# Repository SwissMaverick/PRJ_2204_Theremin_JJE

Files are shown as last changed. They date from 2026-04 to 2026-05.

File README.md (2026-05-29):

# README du projet 2204 Thérémine version 3
## Objectif du projet
Le Théremin est un appareil permettant de générer un signal audible, dont l'amplitude et la fréquence sont contrôlées par l'utilisateur au moyen de deux capteurs de distance.  
L'appareil peut être utilisé sur secteur ou de manière nomade grâce à une batterie interne.  

Grâce la gestuelle des mains par rapport aux capteurs, la fréquence et l'amplitude du signal audio peuvent être modifiées.  

### Journal de travail
Chemin : PRJ_2204_Theremin_JJE\doc\V3

## Versionning
### Version de l'IDE
v6.15  
### Version du compilateur
XC8 (v2.46)  
### PIC utilisé
PIC18F4550-I/PT  
### Caractéristique du PIC18
Fréquence : 48MHz  
Sources d'interruption : 20  
I/O Ports : A, B, C, D, E  
Timers : 4  
PWM modules : 1  
Comm série : USART  
USB modules : 1  
Comparateurs : 2  
Boîtiers : 40-Pin PDIP, 44-Pin QFN, 44-Pin TQFP  
### Bits de configuration
```C
// CONFIG1H : Oscillateur
#pragma config FOSC = INTOSCIO_EC // Oscillateur interne, RA6 et RA7 en E/S numériques
#pragma config FCMEN = OFF        // Moniteur d'horloge de sécurité désactivé
#pragma config IESO = OFF         // Basculement d'oscillateur désactivé

// CONFIG1L
#pragma config PLLDIV = 1       
#pragma config CPUDIV = OSC1_PLL2 
#pragma config USBDIV = 1

// CONFIG2L : Alimentation et Reset
#pragma config PWRT = ON          // Délai de démarrage activé (stabilise l'alim)
#pragma config BOR = ON           // Reset si chute de tension
#pragma config BORV = 3           // Tension du BOR fixée à 2.05V
#pragma config VREGEN = OFF       // Régulateur USB désactivé (pas d'USB utilisé)

// CONFIG2H : Chien de garde (Watchdog)
#pragma config WDT = OFF          // Watchdog désactivé pour le développement

// CONFIG3H : Multiplexage et PORTB
#pragma config CCP2MX = ON        // E/S CCP2 multiplexée avec RC1
#pragma config PBADEN = OFF       // PORTB<4:0> configurés en E/S NUMÉRIQUES au reset
#pragma config LPT1OSC = OFF      // Timer1 configuré pour haute puissance
#pragma config MCLRE = ON         // Broche MCLR activée (Reliée à SW1 sur le schéma)

// CONFIG4L : Paramètres étendus
#pragma config STVREN = ON        // Reset sur débordement de la pile
#pragma config LVP = OFF          // Programmation basse tension DÉSACTIVÉE (Libère RB5)
#pragma config ICPRT = OFF        // Port de débogage ICSP dédié désactivé
#pragma config XINST = OFF        // Jeu d'instructions étendu désactivé
```
## Mise en place du projet
### Déploiement
### Fréquence du PIC18
```C
#define _XTAL_FREQ 8000000
```
### Définition des broches
```C
// Définition des broches
#define LED_DS1      LATEbits.LATE2
#define LED_BAT_RED  LATEbits.LATE1 
#define LED_BAT_GRN  LATEbits.LATE0 
#define BAT_READ     LATAbits.LATA0

// CAPTEUR ULTRASON HORIZONTAL
#define TRIG_H LATCbits.LATC0  // Sortie (On envoie l'impulsion)
#define ECHO_H PORTCbits.RC2   // Entrée (On lit le retour)

// DAC AUDIO (MCP4901)
#define DAC_CS   LATDbits.LATD5 // Chip Select (Active le DAC)
#define DAC_SCK  LATBbits.LATB1 // Horloge SPI
#define DAC_SDI  LATBbits.LATB0 // Données SPI (Sortie logicielle)
```
### Prototypes des fonctions
```C
void Init_Hardware(void);
void DAC_Write(uint8_t valeur);
void ADC_Init(void);
uint16_t ADC_Read_AN1(void);
float Lire_Tension_Batterie(void);
void Surveiller_Tension_Batterie(void);
```

## Explication sur les fonctions implémentées :
### Initialisation  
```C
void Init_Hardware(void) 
{
    // --- OSCILLATEUR (8 MHz) ---
    OSCCONbits.IRCF = 0b111;  
    OSCCONbits.SCS = 0b00;  
    while(!OSCCONbits.IOFS);
    
    // --- GPIO & NUMÉRIQUE ---
    ADCON1 = 0x0F; // Tout en numérique par défaut       
    CMCON = 0x07;             
    
    // Config de la LED de test et des broches de batterie
    TRISEbits.TRISE2 = 0; // RE2 configuré en SORTIE
    LED_DS1 = 0;          // On s'assure qu'elle est éteinte au départ        
    
    TRISEbits.TRISE1 = 0; // LED_BAT_RED en sortie
    TRISEbits.TRISE0 = 0; // LED_BAT_GRN en sortie 
    TRISAbits.TRISA0 = 0; // BAT_READ en sortie
    TRISAbits.TRISA1 = 1; // BAT_LVL (AN1) en entrée
    
    // Config du capteur Ultrason Horizontal
    TRISCbits.TRISC0 = 0; // TRIG_H en SORTIE (On envoie le signal)
    TRISCbits.TRISC2 = 1; // ECHO_H en ENTRÉE (On écoute le capteur)
    TRIG_H = 0;           // On s'assure que le Trigger est à 0 par défaut

    // --- TIMERS (Timer0 pour Blinky) ---
    T0CON = 0b10100001; 
    INTCONbits.TMR0IF = 0; 
    
    // --- DAC AUDIO (SPI Logiciel) ---
    TRISDbits.TRISD5 = 0; // CS en sortie
    TRISBbits.TRISB1 = 0; // SCK en sortie
    TRISBbits.TRISB0 = 0; // SDI en sortie (on force l'entrée matérielle à devenir une sortie !)
    DAC_CS = 1;  // CS désactivé (le DAC est inactif à l'état haut)
    DAC_SCK = 0; // Horloge au repos
    DAC_SDI = 0; // Ligne de données à 0
    
    // Timer 0 (Pour les délais ou futurs clignotements)
    T0CON = 0b10000011; // Prescaler 1:16
    INTCONbits.TMR0IF = 0; 

    // Timer 1 (Le chronomètre pour le capteur Ultrason)
    // 16-bit, Horloge interne, Prescaler 1:4, Timer ON
    T1CON = 0b10100001; 

    // Module de Capture CCP1 (Relié à RC2 / ECHO_H)
    // Mode Capture : se déclenche sur chaque FRONT MONTANT au repos
    CCP1CON = 0b00000101; 

    // Configuration des Interruptions
    PIR1bits.CCP1IF = 0;  // Remise à zéro du drapeau de capture
    PIE1bits.CCP1IE = 1;  // Activation de l'interruption pour CCP1
    
    // Activation des interruptions générales du PIC
    INTCONbits.PEIE = 1;  // Autorise les interruptions périphériques
    INTCONbits.GIE = 1;   // Autorise les interruptions globales
}
```
### Fonction principale
```C
void main(void) 
{
    Init_Hardware();

    uint16_t duree_ticks = 0;
    float distance_cm = 0;
    uint8_t amplitude = 0;

    while(1) 
    {
        mesure_prete = 0;  // On remet notre signal à zéro
        envoyer_trigger(); // On lance un ping
        
        // Le HC-SR04 a besoin de 60ms de repos entre deux tirs pour que
        // l'écho ne rebondisse pas partout dans la pièce
        __delay_ms(60); 

        // Une fois les 60ms passées, l'interruption matérielle a largement eu le 
        // temps de faire son travail en tâche de fond. On peut calculer :
        if (mesure_prete == 1) 
        {
            // Calcul de la différence de temps (gestion du redémarrage du timer)
            if (temps_fin >= temps_depart) 
            {
                duree_ticks = temps_fin - temps_depart;
            } 
            else 
            {
                duree_ticks = (65535 - temps_depart) + temps_fin; 
            }

            // Explication de la formule mathématique :
            // Le Timer1 avance toutes les 2µs (grâce au Prescaler 1:4).
            // Distance standard = Temps(µs) / 58
            // Ici : Distance = (ticks * 2) / 58 => Distance = ticks / 29
            distance_cm = (float)duree_ticks / 29.0f;

            // --- LE TEST ---
            // Si la main est entre 2 cm (minimum du capteur) et 15 cm
            if (distance_cm >= 2 && distance_cm <= 15)
            {
                LED_DS1 = 1; // Allumé : L'obstacle est dans la zone !
            }
            else 
            {
                LED_DS1 = 0; // Éteint : L'obstacle est trop loin
            }
        }
        else
        {
            // MODE ERREUR : L'interruption n'a pas détecté la fin de l'écho !
            // On fait clignoter la LED très brièvement pour signaler un problème
            LED_DS1 = 1;
            __delay_ms(10);
            LED_DS1 = 0;
        }
    }
}
```
### Fonction d'envoi d'impulsion pour le capteur ultrason
```C
void envoyer_trigger(void) 
{
    TRIG_H = 1;
    __delay_us(10); // Impulsion de 10 microsecondes requise par le HC-SR04
    TRIG_H = 0;
}
```
### Fonction d'interruption
```C
void __interrupt() ISR(void) 
{
    // Si l'interruption vient du module de Capture CCP1 (Capteur Ultrason)
    if (PIR1bits.CCP1IF) 
    {
        PIR1bits.CCP1IF = 0; // Remise à zéro du vrai drapeau

        // Si on surveillait le FRONT MONTANT (L'écho vient de s'activer)
        if (CCP1CONbits.CCP1M0 == 1) 
        {
            temps_depart = ((uint16_t)CCPR1H << 8) | CCPR1L; 
            
            PIE1bits.CCP1IE = 0;  // 1. On désactive l'interruption
            CCP1CON = 0b00000100; // 2. On change de direction (Front Descendant)
            PIR1bits.CCP1IF = 0;  // 3. On efface le "faux" drapeau généré
            PIE1bits.CCP1IE = 1;  // 4. On réactive l'interruption
        } 
        // Sinon, c'est le FRONT DESCENDANT (L'écho vient de se couper)
        else 
        {
            temps_fin = ((uint16_t)CCPR1H << 8) | CCPR1L;    
            mesure_prete = 1;
            
            PIE1bits.CCP1IE = 0;  
            CCP1CON = 0b00000101; 
            PIR1bits.CCP1IF = 0;  
            PIE1bits.CCP1IE = 1;  
        }
    }
}
```
### Calculs
**Formule du calcul de la distance par rapport au capteur**  
### $$\frac{\text{Durée impulsion écho} \times 340}{2}$$

## Validation des fonctions implémentées

### Testing :

- **Signaux mesurés**
  
**Clignotement de la LED**
LED_clignote
Ce test s'agissait juste de vérifier les timers ainsi que les prescalers configurés dans le PIC. Le clignotement d'une LED confirmait donc que ces fonctions étaient correctement configurées.
  
Mapping :

CH1 / U2.27 (LED Rouge)

**Premier essai de l'ultrasons avec mauvaise alimentation**
Premier essai ultrasons (fonctionne pas)  
Dans ce cas-là, l'echo restait fixe et était juste représenté par un faible pic. Le problème était que le capteur était alimenté en 3.3V alors qu'il est écrit dans son datasheet qu'il doit être alimenté en 5V. Pour remédier à ce prolème, il a fallu rebrancher l'alim au 5V de la carte. Des capteurs alimentés en 3.3V ont été commandés mais ne sont toujours pas arrivés à l'heure de l'écriture de ce document (29.05.2026).  
  
Mapping :

CH1 / X1.2 (Trigger)

CH2 / X1.3 (Echo)

**Essai avec la bonne alimentation (fonctionnel)**
Essai alim 5V (fonctionne)  
En mettant une alim de 5V. La réponse est beaucoup plus concluante. L'impulsion d'echo correspond beucoup plus à ce qui était attendu. De plus, cet echo varie lorsque l'on met un obstacle devant le capteur. Il a été néanmoins remarqué que la détéction d'une main est effective jusqu'à environ 30cm - 40cm. Au-delà de ces distances, la main est difficilement détectable et il faut mettre une surface plus grande comme la face d'un livre pour que le capteur détecte à nouveau l'obstacle.  
  
Mapping :

CH1 / X1.2 (Trigger)

CH2 / X1.3 (Echo)

**Essai à 10cm**
Essai 10cm  
En mettant la main à 10cm du capteur, il est possible de mesurer l'echo et de vérifier si la distance est correcte.  
  
Mapping :

CH1 / X1.2 (Trigger)

CH2 / X1.3 (Echo)

### $$\frac{\text{Durée impulsion écho} \times 340}{2} = \frac{\text{600us} \times 340}{2} = 0,102m = 10,2cm$$

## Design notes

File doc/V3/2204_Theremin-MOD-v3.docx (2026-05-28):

# Projet ETML-ES – Modification

A remplir par l'initiateur

PROJET:
Entreprise/Client: | ETML-ES | Département: | SLO2
Demandé par (Prénom, Nom): | Philippe Bovey | Date: | 26.06.2023
Objet (No ou réf, pièce, PCB...) | Théremin 2204
Version à modifier:

A remplir par l'exécutant

Auteur (ETML-ES): | Jérémie Jean-Elie | Filière: | SLO
Nouvelle version: | | Date: | 28.05.2026

# 1 Description ou justification

Ce fichier mod permet à l’étudiant de connaitre l’état actuel du projet et qu’il puisse le reprendre sans problème.

# 2 Référence conception

Le cahier de charges du système se trouve sur :

K:\ES\PROJETS\SLO\2204_Theremin\doc\admin\2204_Théremin-CDC-v1.docx$

Le dossier du projet se trouve sur :

K:\ES\PROJETS\SLO\2204_Theremin

Le dossier contenant le projet crée sur MPLAB se trouve sur : K:\ES\PROJETS\SLO\2204_Theremin\soft\2204_Firmware_V2.0_JJE

Le dossier contenant toute la documentation réalisée sur le projet se trouve sur : K:\ES\PROJETS\SLO\2204_Theremin\doc\V3

# 3 Détail des modifications

# | Description | Fait | Approuvé

1 | Nouvelle config des fusibles du PIC18 | OK
2 | Implémentation d’une fonction pour faire clignoter une LED | OK
3 | Implémentation d’une fonction de test des capteurs ultrasons | OK
4 | Changement du modèle de capteur ultrasons. Au départ un capteur avec une alim 5V y était installé. Mais toute la carte est en 3.3V. Un capteur ultrasons en 3.3V doit être installé. | NOK
5 | Comm avec l’ADC | NOK
6 | Génération d’un son | NOK
7
8

# 4 Remarques

Il a fallu reprendre le codage du projet de 0 étant donné que le travail qui avait précédé celui-ci ne faisait pas fonctionner la carte. Les fusibles et registres du PIC18 ont donc été configurer pour générer un timer permettant de faire fonctionner certaines fonctionnalités de la carte. Les capteurs ultrasons ont pu être testés. Il a été remarqué que ces capteurs disposaient de la mauvaise alim. Lorsque ceux-ci ont été correctement alimentés, la distance a pu être mesurée de manière précise. Une fonction pour essayer de communiquer avec l’ADC pour essayer d’émettre un son a été écrite mais celle-ci n’est pas fonctionnelle. La fonction de détection de distance a juste été faite pour le capteur horizontal mais le fonctionnement est strictement le même pour le capteur vertical.

Une mise en garde semble nécessaire pour l’utilisation de capteurs ultrasons. En effet ceux-ci ne semblent pas correctement détecter une main au-delà d’environ 30cm. Ce détail peut donc limiter l’amplitude de mouvement possible pour jouer des notes.

Ce qu’il reste à faire pour avoir un prototype fonctionnel est de pouvoir communiquer avec l’ADC et d’émettre un son, puis d’allier la mesure de distance à la génération du son.

# 5 Convention de nommage et liens

Le nom de ce fichier doit être unique et doit donc contenir le numéro du projet et un numéro consécutif de modification avec le format suivant :

aaii_MOD_nn.docx

ou

NomProjet_MOD_nn.docx

avec :

- MOD : pour modification
- aaii : numéro de projet, exemple 1708 pour projet de 2017 no 08
- NomProjet : Si le projet n’est pas numéroté ou mandat de client.
- nn : numéro de modification. La première est 01

Exemples :

- 1708_MOD_01.docx 1ere modification pour le projet 1708
- 1708_MOD_02.docx 2e modification pour le projet 1708
- CapteurVolets_MOD_01.docx Cas de projet externe

Le schéma et/ou les documents de production de la pièce ou du PCB se référeront à ce document dans les cartouches.

Si un nouveau projet reprend un design d’un autre projet, créer un document de modification numéro 00. Ainsi, on pourra décrire les modifications initiales dans le fichier.

Exemple :

- 1803_MOD_00.docx Modification initiale pour le nouveau projet 1803 à partir d’un autre projet (par ex. 1708)

## 5.1 Stockage du fichier

Ce fichier sera stocké à la racine du dossier \doc\V3 d’un projet.

Ainsi, tous les fichiers de modifications des pièces ou PCBs faisant partie du projet sont centralisés dans le même répertoire. La numérotation devient implicite.

JMO – Nov 2018Projet-MOD-v1.docxPage 2

ECOLE SUPERIEURE ELCO – SLO

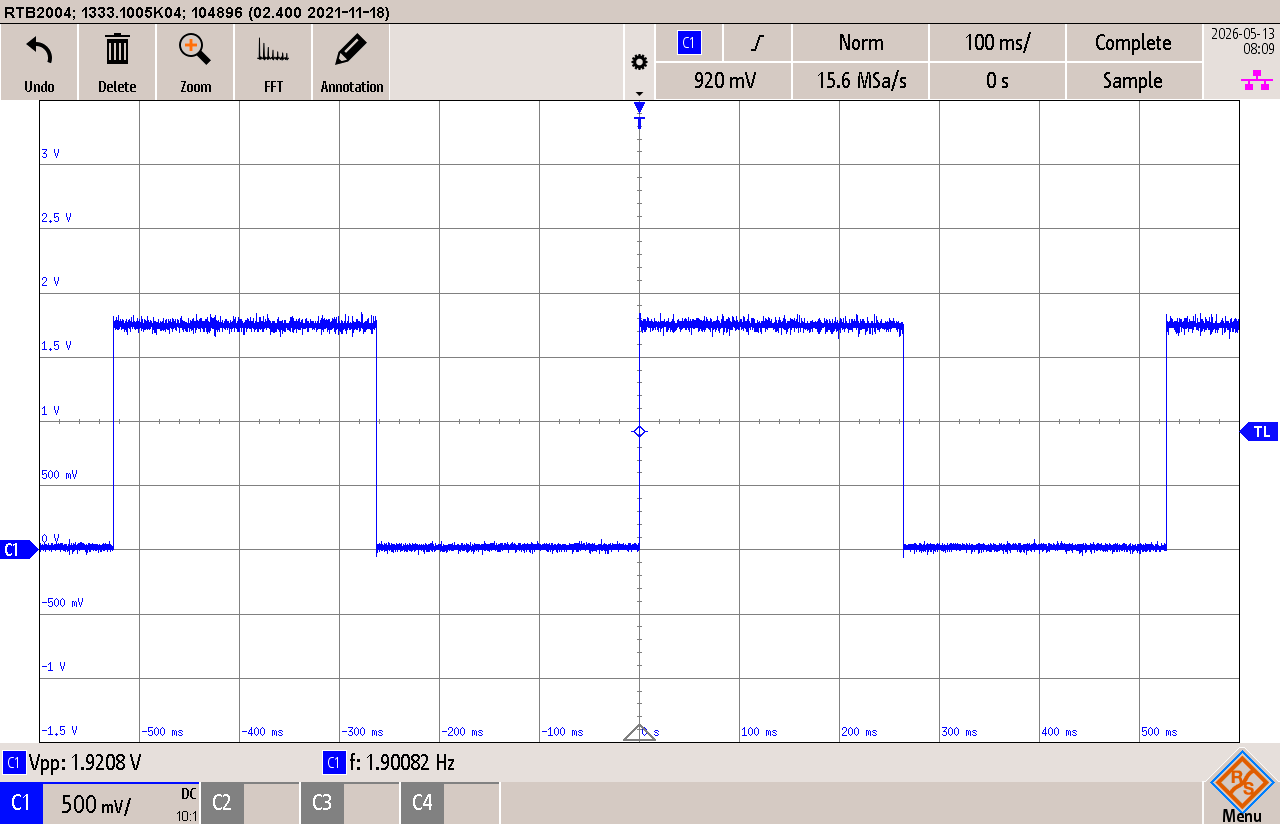
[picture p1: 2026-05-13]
doc/V3/Screenshots/LED clignote/LED_clignote.png

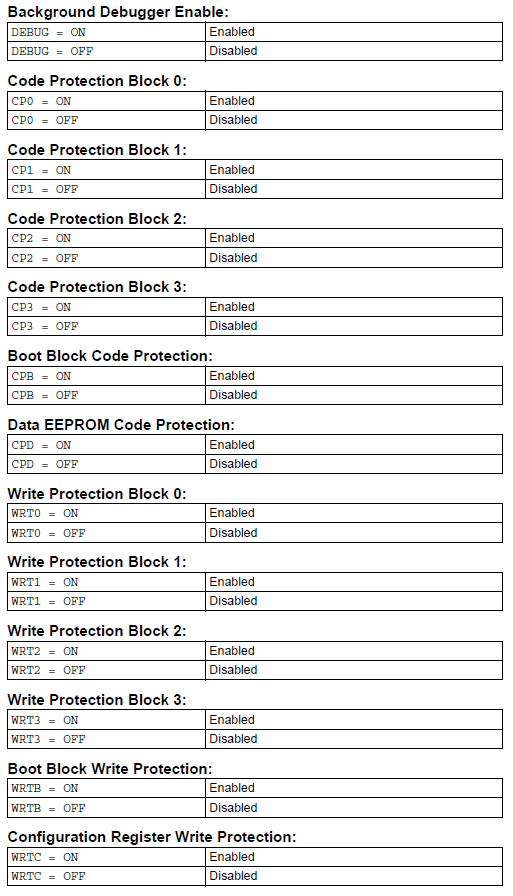
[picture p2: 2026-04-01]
doc/V3/Screenshots/Config PIC18/Config_4.png

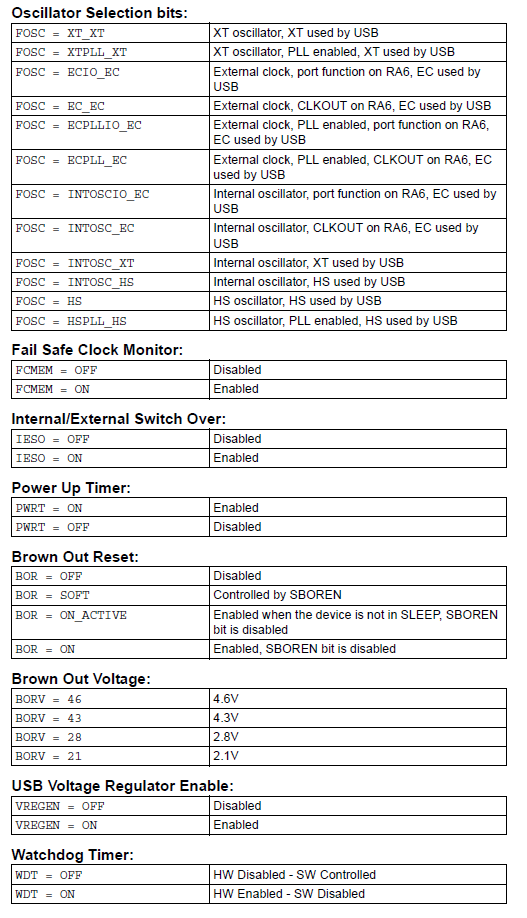
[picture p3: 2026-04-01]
doc/V3/Screenshots/Config PIC18/Config_2.png

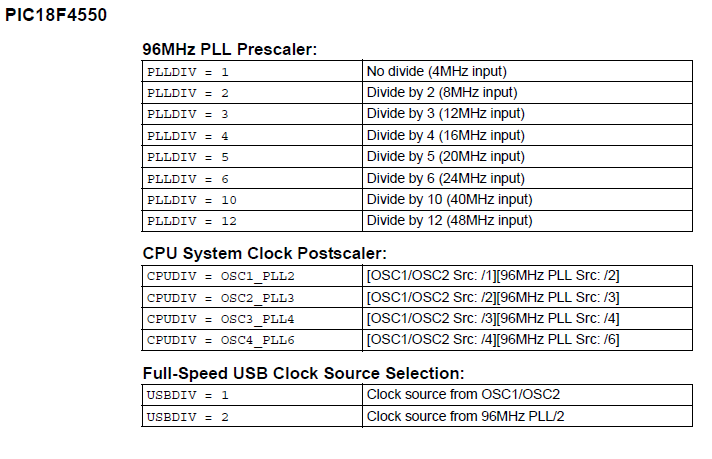
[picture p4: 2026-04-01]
doc/V3/Screenshots/Config PIC18/Config_1.png

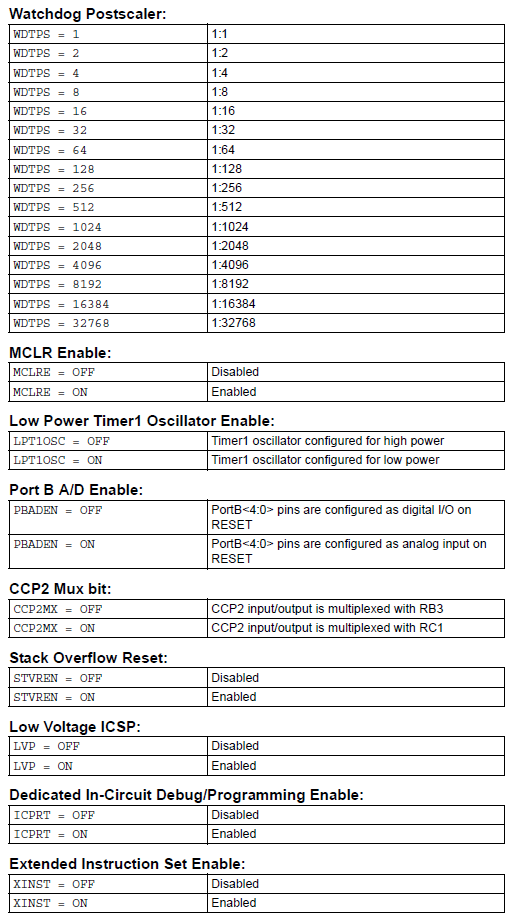
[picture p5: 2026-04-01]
doc/V3/Screenshots/Config PIC18/Config_3.png

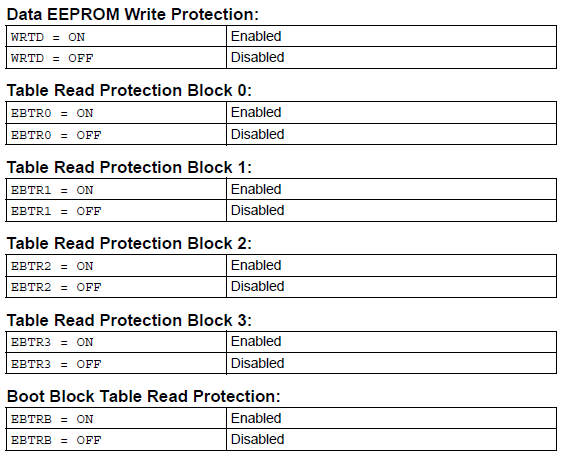
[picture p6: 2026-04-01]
doc/V3/Screenshots/Config PIC18/Config_5.png

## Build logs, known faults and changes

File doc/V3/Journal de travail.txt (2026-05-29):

Journal de travail projet PROG 2204 Theremine :

11.02.2026 : Discussions avec M.Bovey sur le déroulement du projet. Etablissement d'une liste des tâches.
Création d'une machine d'état globale.

25.02.2026 : Machine d'état globale

04.03.2026 : Validation de la machine d'états

11.03.2026 : Listing des registres du PIC18

18.03.2026 : Revue avec M.Merlini + planif des tâches à suivre

25.03.2026 : Absent

01.04.2026 : 

22.04.2026 : Recherche sur la configuration des registres des oscillateurs, timers et GPIO

29.04.2026 : Simplification du code pour n'avoir que deux fichiers : 
"hardware.c" qui sert à configurer les registres
"main.c" qui sert à écrire les fonctions du code

06.05.2026 : Écriture des fonctions pour le clignotement de la LED. Recherches sur le problème de connexion au debugger. Il se trouve que j'avais le mauvais ICD. Une fois celui-ci monté, la connexion a pu se faire.

13.05.2026 : Code du clignotement non fonctionnel en début de cours. Résolution du problème. La port addressé n'était pas le bon. Après la résolution du problème, la LED a bien pu être clignotée.

20.05.2026 : Réussite du test avec le capteur ultrasons. Le problème était que le capteur était alimenté en 3.3V alors qu'il nécéssitait du 5V. Il a été décidé de commander des capteurs ultrasons compatibles avec une alim en 3.3V. Dans le futur, une alim 5V sur la carte ne sera plus utile étant donné que tout le reste est alimenté en 3.3V.

27.05.2026 : Essai d'un code pour allumer une LED lorsque la distance détectée passait sous un certain seuil (non fonctionnel). Tentatives de communication avec l'ADC (non fonctionnel)

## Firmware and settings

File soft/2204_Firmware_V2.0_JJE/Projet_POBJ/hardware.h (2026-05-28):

/* Microchip Technology Inc. and its subsidiaries.  You may use this software 
 * and any derivatives exclusively with Microchip products. 
 * 
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
 * IN NO EVENT WILL MICROCHIP BE LIABLE FOR ANY INDIRECT, SPECIAL, PUNITIVE, 
 * INCIDENTAL OR CONSEQUENTIAL LOSS, DAMAGE, COST OR EXPENSE OF ANY KIND 
 * WHATSOEVER RELATED TO THE SOFTWARE, HOWEVER CAUSED, EVEN IF MICROCHIP HAS 
 * BEEN ADVISED OF THE POSSIBILITY OR THE DAMAGES ARE FORESEEABLE.  TO THE 
 * FULLEST EXTENT ALLOWED BY LAW, MICROCHIP'S TOTAL LIABILITY ON ALL CLAIMS 
 * IN ANY WAY RELATED TO THIS SOFTWARE WILL NOT EXCEED THE AMOUNT OF FEES, IF 
 * ANY, THAT YOU HAVE PAID DIRECTLY TO MICROCHIP FOR THIS SOFTWARE.
 *
 * MICROCHIP PROVIDES THIS SOFTWARE CONDITIONALLY UPON YOUR ACCEPTANCE OF THESE 
 * TERMS. 
 */

/* 
 * File:   
 * Author: 
 * Comments:
 * Revision history: 
 */

// This is a guard condition so that contents of this file are not included
// more than once.  
#ifndef HARDWARE_H
#define	HARDWARE_H  

// Librairies communes
#include <xc.h>
#include <stdint.h>

// Fréquence du PIC (utile pour __delay_ms)
#define _XTAL_FREQ 8000000

// Définition des broches
#define LED_DS1      LATEbits.LATE2
#define LED_BAT_RED  LATEbits.LATE1 
#define LED_BAT_GRN  LATEbits.LATE0 
#define BAT_READ     LATAbits.LATA0

// CAPTEUR ULTRASON HORIZONTAL
#define TRIG_H LATCbits.LATC0  // Sortie (On envoie l'impulsion)
#define ECHO_H PORTCbits.RC2   // Entrée (On lit le retour)

// DAC AUDIO (MCP4901)
#define DAC_CS   LATDbits.LATD5 // Chip Select (Active le DAC)
#define DAC_SCK  LATBbits.LATB1 // Horloge SPI
#define DAC_SDI  LATBbits.LATB0 // Données SPI (Sortie logicielle)

// Prototypes
void Init_Hardware(void);
void DAC_Write(uint8_t valeur);
void ADC_Init(void);
uint16_t ADC_Read_AN1(void);
float Lire_Tension_Batterie(void);
void Surveiller_Tension_Batterie(void);

#endif	/* XC_HEADER_TEMPLATE_H */

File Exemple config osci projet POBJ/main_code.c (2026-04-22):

//----------------------------------------------------------------------------//
// Nom du projet 		:	Reglage Encodeur
// Nom du fichier 		:   main_code.c
// Date de création 	:   04.12.2019
// Date de modification : 	02.12.2020
// 
// Auteur 				: 	Philou (Ph. Bovey) 
//                      :   Kevin Bougnon 
//
// Description 			: 	Canevas pour le laboratoire de réglage avec la carte
//                          1601_HalfBridge 
//                         
// Remarques			: 
// 	    chemin pour trouver le headerfile 
//		C:\Program Files\Microchip\MPLAB C30\support\dsPIC33F\h
//
//      Hardware de la carte => ATTENTION PIC MONTER SUR LA CARTE DSPIC33FJ128MC802
//      K:\ES\PROJETS\SLO\1601x_HalfBridge3x\doc 
//
//	    doc pour le DSP : 
//		K:\ES\PROJETS\SLO\1601x_HalfBridge3x\doc\datasheets
//
//      doc pour la configuration du PWM : 
//      https://ww1.microchip.com/downloads/en/DeviceDoc/70187E.pdf
//
//      doc pour la configuration du module de quadrature 
//      https://ww1.microchip.com/downloads/en/DeviceDoc/70208C.pdf
//
//----------------------------------------------------------------------------//

//--- librairie à inclure ---// 
#if defined(__dsPIC33F__)
#include "p33Fxxxx.h"
#endif

#include <stdio.h>
#include <stdlib.h>
#include <stdint.h>
#include <xc.h>                             // appel de directive du compilateur C pour le Dspic 
#include "math.h"

#include "configuration_bitsSettings.h"     // configuration des bits settings pour l'oscillateur 
#include "configOscillateur.h"              // configuration de l'oscillateur interne du Dspic
#include "configTimer.h"                    // configuration des timers


#define NBR_PAS_MAX_ECHANTILLONER 1024

int8_t flagInterrupt = 0;

unsigned int Count;

void __attribute__((interrupt,no_auto_psv)) _T1Interrupt( void )
{
    
	
    IFS0bits.T1IF = 0;
    T1CONbits.TON = 0;
    
    
    
    if (flagInterrupt == 0) 
    {
        //LATBbits.LATB15 = 0;//~LATBbits.LATB15;
        flagInterrupt = 1; 
    }
    
    ~LATBbits.LATB15; //LATBbits.LATB15 = 0;//~LATBbits.LATB15;

          

   	
    //	
    
    /*Count++;
	if(Count == 1000)
	{
		    Count		   = 0;  
			LATBbits.LATB15 = ~LATBbits.LATB15;		    
	}*/

    TMR1          = 0;
	T1CONbits.TON = 1;
	
    /*IFS0bits.T1IF = 0;
    T1CONbits.TON = 0;
    
        TMR1          = 0;
	T1CONbits.TON = 1; */
	/* reset Timer 1 interrupt flag */
 	
}

int main(int argc, char** argv) 
{
   //-- déclaration de variable --// 
    int16_t compteurQuadra = 0; 
    
    int32_t posk = 0, posk_1 = 0, retenu = 0;
    
    
    int32_t position_angle, compteur = 0;
    
    float position; 
    
	RCONbits.SWDTEN=0;            /* Disable Watch Dog Timer*/
	
    // Configure Oscillator to operate the device at 40Mhz
    // Fosc= Fin*M/(N1*N2), Fcy=Fosc/2
    // Fosc= 8M*40/(2*2)=80Mhz for 8M input clock
    //OSCCONbits.COSC = 0;                // Fast RC Oscillateur avec PLL
    //OSCCONbits.CLKLOCK	= 1;			// ne veut pas changer la clock après configuration 
    //OSCCONbits.OSWEN = 1;               // ne veut pas changer la source de la clock (interne/externe)
	
    /*PLLFBD=158;					// M=38
	CLKDIVbits.PLLPOST=5;		// N1=2
	CLKDIVbits.PLLPRE=0;		// N2=2*/
    
    PLLFBDbits.PLLDIV 	= 158;			// M = 158 => 158+2 => 160   -> voir remarque 
    CLKDIVbits.PLLPRE 	= 5; 			// N1 = 5 => 5+2 = 7	-> voir remarque 
    CLKDIVbits.PLLPOST 	= 0; 			// N2 = 2 	-> voir remarque 
	
    //-- registre PLLFBD --//
    

    // Clock switching to incorporate PLL
	__builtin_write_OSCCONH(0x01);		// Initiate Clock Switch to Primary
                                        // Oscillator with PLL (NOSC=0b011)
	__builtin_write_OSCCONL(0x01);		// Start clock switching
	//while (OSCCONbits.COSC != 0b011);	// Wait for Clock switch to occur	


   /*Initialize the Ports */    
    //-- initialisation de ports A et B tout en sortie 
    TRISA = 0x0000;
    //TRISB = 0x0000;
    
    //-- initilaisation de entrée en quadrature --// 
    // entrée en mode quadrature RP6 -> QA
    //RPINR14bits.QEA1R = 6;     // entrée RP6 = QA 
    // entrée en mode quadrature RP5 -> QB
    //RPINR14bits.QEA1R = 5;     // entrée RP5 = QB
    
    //QEI1CONbits.UPDN_SRC = 1;   // définit le sens de lecture 
    //QEI1CONbits.TQCS = 0;       // clock source Tcyc = 36.85MHz
    
    
    //LATA  = 0x0000;
    //PORTA = 0x0000;
 
    Timer1Init();
    /*InitOscillateur(); */
    //Timer1Init();
    
    
    //configuration pwm
    
    P1TCONbits.PTMOD = 0;   // free Running mode
    P1TCONbits.PTCKPS = 0;  // prescelaire configurer à 1 : 1 / fcyc = tcyc 
    P1TCONbits.PTOPS = 0;   // postscaler 1 : 1 
    
    PWM1CON1 = 0;           // pour un clear du regitstre 
    PWM1CON1bits.PEN1H = 1; 
    PWM1CON1bits.PEN1L = 0; 
    PWM1CON1bits.PMOD1 = 1; 
    
    
    // registre de 16bits pour la mise à jour de la péridode du PWM 
    // période : 100kHz même chose que le timer 1 => 10us (T_PWM)
    // tcyc = 1 / Fcyc = 1 / 36.85 Mhz = 27ns 
    // N-Tic_PWM = T_PWM / Tcyc = 10us / 27ns = 370 tic 
    P1TPER = 370; 
    
    // PWM à 60% (la mise à jour ce fait à 2 x la valeur de la période)
    // ex : (2 x P1TPER + 2) * rapport cyclique (60/100)
    P1DC1 = (((2 * P1TPER) + 2) * 60)/100; 
    
    // MAJ du Timer Counter lié au PWM à zéro + activation mode PWM  
    P1TMR = 0; 
    P1TCONbits.PTEN = 1;        // activer le PWM 
    
    
    //-- configuration module quadrature 
    //-- configuration des entres A et B encodeur 
    RPINR14bits.QEA1R = 6;      // correspond à la pin RP6 => A
    RPINR14bits.QEB1R = 5;      // correspond à la pin RP5 => B 
    
    
    // QEIxCON 
    QEI1CONbits.QEIM = 7;   // Quadrature mode 4 
    QEI1CONbits.PCDOUT = 1; 
    QEI1CONbits.POSRES = 0; 
    //QEI1CONbits.UPDN_SRC = 1; 
    
    DFLT1CONbits.QEOUT = 0; 
    
    
    MAX1CNT = 65535; 
    
    //-- lecture du registre compteur --// 
    //compteurQuadra = POS1CNT; 
    
    
    
    
    
    
    
    
    // DFLTxCON
    
    
    // POSxCNT 
    
    // MAXxCNT 
     
    
    
    while(1)
    {
        //-- lecture du flag d'interruption 
        if(flagInterrupt == 1)
        {
            posk = POS1CNT; 
            
            
            
            
            if (posk - posk_1 >= 32768)
            { 
                retenu -= 1;  
            }
            else if(posk - posk_1 <= -32768)
            {
                retenu += 1; 
            }
            
            position = retenu * pow(2, 16) + posk; 

            posk_1 = posk; 
            
            flagInterrupt = 0; 
            
            if(compteur >= 100000)
            {
                compteurQuadra = 1; 
            }
            
            compteur++; 
        }
        
        
        //LATBbits.LATB15 = 0;//~LATBbits.LATB15;
        //LATBbits.LATB15 = 1;//~LATBbits.LATB15;
    }

    return (EXIT_SUCCESS);
}
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

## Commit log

2026-02-25 Create Journal de travail.txt
2026-03-04 mmmmh yes
    [configuration_bitsSettings.h]
2026-04-22 Add dsPIC33F oscillator/timer example files
    [configuration_bitsSettings.h]
2026-04-22 Update Journal de travail.txt
2026-04-29 Update projet
    [configuration_bitsSettings.h]
